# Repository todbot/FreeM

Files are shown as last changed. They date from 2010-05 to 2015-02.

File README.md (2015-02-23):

# FreeM: aka "BlinkM Battery Remote"
======================================

https://www.youtube.com/watch?v=3fSsRGN1ip0

(http://www.youtube.com/watch?v=3fSsRGN1ip0)

Documentation is kind of sparse at the moment.
So this kit is aimed at more advanced users right now.

The firmware "freem_a2" is the one you should use.
If you are using the FreeM Kit from FunGizmos, the chip is preprogrammed.

Otherwise, tune the Makefile for your AVR programmer if you're not using an
AVRISP mkII.  Then type "make program" to compile and program your chip.

From the header of the firmware, these are the basic features:
```
 * Remote control functions:  (Sony TV remotes only right now)
 * - POWER     - stop script & turn off blinkm
 * - CH  UP/DN - solid hue mode, cycle hue if held down
 * - VOL UP/DN - brightness up/down
 * - ENTER     -
 * - MUTE      - 
 * - Num keys  - do something interesting
 *   1 - random slowly changing mood light (calc'd in FreeM)
 *   2 - fast random colors
 *   3 - flashing beacon, use ch up/dn to change hue, press 3 again to start
 *   4 - yellow
 *   5 - aqua
 *   6 - purple
 *   7 - dim white
 *   8 - med white
 *   9 - bright white
 *   0 - play script 0 on BlinkM
 * 
 * Data Mode:
 * - Sending keycode of 0x07F7 escapes into data mode
 * - Sending keycode of 0x07F8 escapes out of data mode
 * - data format is: len,byte_0,byte_1,byte_2,...byte_len-1
 * - if len==4, then command is sent as a straight 3-arg BlinkM command,
 *   e.g. send binary 0x7F7,'c',0xFF,0x00,0xFF to fade BlinkM to purple
 * - data mode is still buggy and aggravating, but maybe interesting
 *
 * "BlinkM Battery Remote" - battir3 pcb layout
 * ---------------------------------------------
 * attiny45       -- function
 * pin 1 -- PB5   -- RESET
 * pin 2 -- PB3   -- PHOTOCELL  (unused)
 * pin 3 -- PB4   -- IRDETECT
 * pin 4 -- GND   -- GND
 * pin 5 -- PB0   -- SDA/MOSI    -- 
 * pin 6 -- PB1   -- MISO        -- LED1 & serial TX out
 * pin 7 -- PB2   -- SCK/SCL     -- 
 * pin 8 -- VCC   -- VCC
```

Assembly Tip:
   LED orientation: Cathode (short lead) faces the "led1" silkscreen printing on the PCB. 

Contact tod at thingm.com if you have any questions.

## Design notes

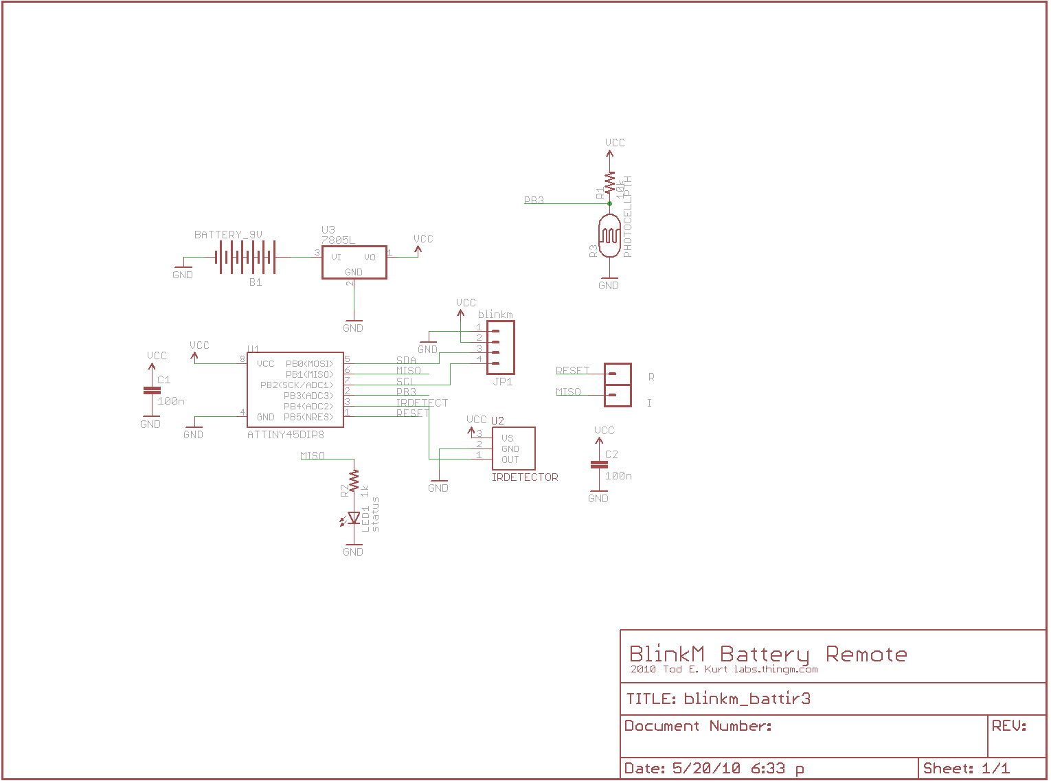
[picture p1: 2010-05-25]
schematic/blinkm_battir3.png

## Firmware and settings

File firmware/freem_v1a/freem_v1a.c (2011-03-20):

/**
 * freem_v1a.c -- FreeM: BlinkM Battery Remote firmware
 *
 * 
 * 2010, Tod E. Kurt, thingm.com
 *
 * Remote control functions:  (Sony TV remotes only right now)
 * - POWER     - stop script & turn off blinkm
 * - CH  UP/DN - solid hue mode, cycle hue if held down
 * - VOL UP/DN - brightness up/down
 * - ENTER     -
 * - MUTE      - 
 * - Num keys  - do something interesting
 *   1 - random slowly changing mood light (calc'd in FreeM)
 *   2 - fast random colors, ch up/dn to change speed
 *   3 - flashing beacon, use ch up/dn to change hue, press 3 again to start
 *   4 - fixed color, hold to change hue, vol/up dn to change brightness
 *   5 - flash once
 *   6 - purple
 *   7 - dim white, hold to change bright
 *   8 - med white, hold to change bright
 *   9 - bright white, hold to change bright
 *   0 - play script 0 on BlinkM
 * 
 *
 * CtrlM IR protocol:
 * ------------------
 * CtrlM Commands are 8 bytes long. 
 * These 8 bytes are sent out as two 32-bit word packets, 
 * using a modified 32-bit version of the Sony IR protocol.
 * Consisting of the bytes:
 * byte0 -- 0x55        - start byte
 * byte1 -- freem_addr  -
 * byte2 -- blinkm_addr -
 * byte3 -- blinkm_cmd  - 
 * byte4 -- blinkm_arg1 - blinkm arg1 (if not used, set to 0)
 * byte5 -- blinkm_arg2 - blinkm arg2 (if not used, set to 0)
 * byte6 -- blinkm_arg3 - blinkm arg3 (if not used, set to 0)
 * byte7 -- checksum    - simple 8-bit sum of bytes 0-6
 *
 *
 * buffer layout is like:  (na == don't matter, set to zero)
 *                  buf[0], buf[1],     buf[2],      [3],  [4], [5], [6],  [7]
 *  std command:     {0x55,  freem_addr, blinkm_addr, cmd,  a1,  a2,  a3,   chk}
 *  write freemaddr: {0x55,  freem_addr, 0xff,        0xff, na,  na,  na,   chk}
 *  set color spot:  {0x55,  freem_addr, 0xfe,        pos,  a1,  a2,  a3,   chk}
 *  play color spot: {0x55,  freem_addr, 0xfd,        pos, cmd,  na,  na,   chk}
 *
 *
 * Some LinkM.sh commands to try: (0x21 == '!'):
 *
 * Fade to purple (0xff,0x00,0xff):
 * ./linkm.sh -v --cmd "0x21,0x55,0,0,'c',0xff,0x00,0xff,0xb6" 
 *
 * Set colorspot 3 to 0x00,0xff,0xff:
 * ./linkm.sh -v --cmd "0x21,0x55,0,0xfe,3,0x00,0xff,0xff,0x54" 
 *
 * Play colorspot 3: 2nd way gives command, could be 'p'lay script
 * ./linkm.sh -v --cmd "0x21,0x55,0,0xfd,3,0x00,0x00,0x00,0x55" 
 * ./linkm.sh -v --cmd "0x21,0x55,0,0xfd,3,'c',0x00,0x00,0xb8" 
 *
 * Can also do: (with new CtrlM firmware that supports '^' and '*', 0x2a='*')
 * ./linkm.sh -v --cmd "0x2a,3,'p',0" 
 *
 * And, Set Colorspot:
 * ./linkm.sh -v --cmd "0x5e,3,0x98,0x76,0x54"  // with new ctrlm '^' == 0x53
 * ./linkm.sh -v --cmd "0x21,0x55,0,0xfe,3,0x98,0x76,0x54,0xb8" // by hand
 * 
 *
 * FreeM ATtiny85 pinout
 * ----------------------
 * attiny85       -- function                         -- header label
 * pin 1 -- PB5   -- RESET                            --  R
 * pin 2 -- PB3   -- PHOTOCELL  (unused)              -- 
 * pin 3 -- PB4   -- IRDETECT                         --  
 * pin 4 -- GND   -- GND                              --  -
 * pin 5 -- PB0   -- SDA/MOSI                         --  d 
 * pin 6 -- PB1   -- MISO  -- LED1 / serial TX out    --  I
 * pin 7 -- PB2   -- SCK/SCL                          --  c
 * pin 8 -- VCC   -- VCC                              --  +
 *
 */

#include <avr/io.h>
#include <avr/interrupt.h>
#include <avr/eeprom.h>
#include <util/delay.h>    // for _delay_ms()
#include <stdint.h>        // for types like uint8_t, etc.
#include <stdlib.h>        // for rand()

// set DEBUG to 0 to disable all debug info and save code space
// set DEBUG to 1 to enable serial debugging on pin 6 (PB1)
// set DEBUG to 2 to enable serial logging off all keys received 
#define DEBUG 0
#define DEBUG_IR 0

#define LED_PIN  PB1
#define LED_PORT PORTB
#define LED_DDR  DDRB

// these must be defined before including i2cmaster_bitbang
#define I2C_DDR  DDRB
#define I2C_PIN  PINB
#define I2C_PORT PORTB
#define I2C_CLK  PB2    
#define I2C_DAT  PB0

// these must be defined before inclding irsony
#define IR_RCV   PB4
#define IR_PORT  PORTB
#define IR_DDR   DDRB
#define IR_PIN   PINB


#if DEBUG>0
// must define this before including softuart.h
#if F_CPU == 500000
#define _baudRate  2400   // if F_CPU=500kHz, doesn't work at other baudrates
#endif
#if F_CPU == 8000000
#define _baudRate  38400  // if F_CPU=8MHz
#endif
#include "softuart.h"
#else  // if DEBUG==0 nuke the func calls so they're just ignored
#define softuart_init()
#define softuart_putc(x)
#define softuart_puts(x)
#define softuart_putsP(x)
#define softuart_printHex(x)
#define softuart_printHex16(x)
#endif


#include "i2cmaster_bitbang.h"
#include "irsony.h"


// I2C address of blinkm, or 0 to address all blinkms
uint8_t i2csendaddr = 0;

#include "blinkm_funcs.h"   // uses i2csendaddr


 //  The timing information for timer to fire periodically 
#if F_CPU == 500000
#define MILLIS_PER_T1OVF       4      // actually 4.1msec
#endif
#if F_CPU == 8000000
#define MILLIS_PER_T1OVF       2      // actually 4.048 msec
#endif

static volatile uint32_t millis = 0;  // current time, set by timer ISR 


//-----------------------------------------------------

#define FADESPEED_DEFAULT    10
#define FADESPEED_RANDMOOD    2
#define FADESPEED_RANDFAST  100

#define MILLIS_MOOD        4000
#define MILLIS_FAST         300

#define KEYMILLIS_MIN       200
#define KEYMILLIS_HOLD     1200 // millis to be considered a hold press

// the different modes FreeM can be in
enum {
    MODE_OFF,
    MODE_RANDMOOD,
    MODE_RANDFAST,
    MODE_FLASH,
    MODE_FLASHONCE,
    MODE_NUMKEY,
    MODE_WHITE,
    MODE_HSB,
    MODE_PLAYSCRIPT,
};
uint8_t mode = MODE_OFF; 

uint32_t changemillis;   // the last time we changed, for RANDMOOD, etc.
uint32_t changemillisdiff;

uint16_t key;            // keypress
uint16_t keylast;       // the previous keypress
uint32_t keylast_millis;
uint32_t keymillis;      // last time a key was pressed
uint8_t keyheld;


uint8_t  hue = 0;        // current hue
uint8_t  bri = 255;      // current brightness
uint8_t  bris;

// address of FreeM
uint8_t freem_addr  = 0x80;

// buf to store copy of incoming data packet
uint8_t buf[8];

typedef struct _rgb_t {
    uint8_t r;
    uint8_t g;
    uint8_t b;
} rgb_t;

/*  no, cannot do this because ctrlm IR protocol doesn't have enough bytes
typedef struct _blinkm_cmd_t {
    uint8_t c;
    uint8_t a1;
    uint8_t a2;
    uint8_t a3;
} blinkm_cmd_t;
*/

// address of this FreeM
uint8_t  ee_freem_addr         EEMEM = 0x7d;  // FIXME: make this match freem_ad
rgb_t ee_colorspots[16] EEMEM;


// -----------------------------------------------------

static void statled_set(uint8_t v)
{
    if(v) LED_PORT |=  _BV( LED_PIN );
    else  LED_PORT &=~ _BV( LED_PIN );
} 
static void statled_toggle(void)
{
    LED_PORT ^= _BV(LED_PIN);
}

// a little hello fanfare
static void fanfare( uint8_t times ) 
{
    for( int i=0;i<times; i++ ) {
#if DEBUG > 0
        softuart_putc('*');
#else
        statled_set(1);
#endif
        blinkm_setRGB( 0x09,0x09,0x09);
        _delay_ms(150);
#if DEBUG > 0
#else
        statled_set(0);
#endif
        blinkm_setRGB( 0x00,0x00,0x00);
        _delay_ms(150);
    }
}


//
// Parse the key presses from IR remote
//
static void handle_key(void)
{
    if( (millis - keylast_millis) > KEYMILLIS_HOLD ) {
        keyheld = 0;
    }

    key = ir_getdata( buf );
    if( key == IR_NONE ) {       // no IR data of any kind
        return;
    }
    
    if( key == IR_GOT_DATA ) {  // got CtrlM 8-byte packet
#if DEBUG >0
        softuart_putsP("ctrlm:");
        //softuart_printHex( buf[0] ); softuart_putc(',');  // start byte 0x55
        softuart_printHex( buf[1] ); softuart_putc(',');    // freem_addr
        softuart_printHex( buf[2] ); softuart_putc(',');    // blinkm_addr
        softuart_printHex( buf[3] ); softuart_putc(',');    // blinkm_cmd
        softuart_printHex( buf[4] ); softuart_putc(',');    // blinkm_arg1
        softuart_printHex( buf[5] ); softuart_putc(',');    // blinkm_arg2
        softuart_printHex( buf[6] ); softuart_putc(':');    // blinkm_arg3
        //softuart_printHex( buf[7] ); softuart_putc('\n'); // checksum
#else
        statled_set(1);
#endif

        // reminder, buffer is like: {0x55,faddr,baddr, cmd,  a1, a2, a3, chk}
        //                           buf[0], [1],  [2], [3], [4],[5],[6], [7]
        mode = MODE_OFF;
        // set freem addr cmd
        if( buf[2] == 0xff && buf[3] == 0xff ) {   // FIXME: document this!
            softuart_putsP("new freem addr\n");
            freem_addr = buf[1];
            eeprom_write_byte( &ee_freem_addr, freem_addr ); // write address
            fanfare(5);  // let people know we did the deed
        }
        // check freem addr to see if its mine or broadcast
        else if( buf[1] == freem_addr || buf[1] == 0 ) {  // me or broadcast
            
            // set colorspot 
            if( buf[2] == 0xfe ) {       // 0xfe == set color slot freem cmd
                uint8_t pos = buf[3];
                rgb_t spot;  
                spot.r = buf[4]; spot.g = buf[5]; spot.b = buf[6];
#if DEBUG >0
                softuart_putsP("set colorspot");
                softuart_printHex(pos);
                softuart_putc(' ');
                softuart_printHex( (int) &(ee_colorspots[pos]) );
                softuart_printHex(spot.r);
                softuart_printHex(spot.g);
                softuart_printHex(spot.b);
#endif
                eeprom_write_block( &spot, &(ee_colorspots[pos]),sizeof(rgb_t));
                // FIXME: flash stat LED in recognition
            }
            // play colorspot
            else if( buf[2] == 0xfd ) {  // 0xfd == play color slot freem cmd
                uint8_t pos = buf[3];
                uint8_t cmd = buf[4]; 
                rgb_t spot;
                eeprom_read_block(  &spot, &(ee_colorspots[pos]),sizeof(rgb_t));
#if DEBUG >0 
                softuart_putsP("play colorspot");
                softuart_printHex(pos); 
                softuart_putc(' '); 
                softuart_printHex( (int) &(ee_colorspots[pos]) );      
                softuart_printHex(spot.r);
                softuart_printHex(spot.g);
                softuart_printHex(spot.b);
#endif
                if( cmd==0 ) { cmd = 'c'; }
                blinkm_sendCmd3( cmd, spot.r, spot.g, spot.b );
            }
            else { // normal cmd
                softuart_putsP("me!");
                i2csendaddr = buf[2];
                if( buf[3] == 'f' ) {   // FIXME: hack
                    blinkm_setFadespeed( buf[4] );  
                } else { 
                    blinkm_sendCmd3( buf[3], buf[4], buf[5], buf[6] );
                }
            }
        }
        
#if DEBUG >0
        softuart_putc('\n');
#else 
        statled_set(0);
#endif
        return;  // done with data mode, don't continue on

    } // if( key == IR_GOT_DATA )

    //
    // Otherwise, it's an RC code
    //
    // okay, we have these cases:
    // no presses for long time, then keypress
    // hold-down key, same key every 50ms or so
    // press key, wait a little bit, press key again
    // press key, press another key

    if( key == keylast ) {  // same key
        if( (millis - keylast_millis) < KEYMILLIS_MIN ) { // a repeat
            if( millis - keymillis > KEYMILLIS_HOLD ) { // since start of key
                keyheld = 1;
            }
        }
        else {             // or press and press again, reset key start time
            keymillis = millis;
        }
    }
    else {                  // a new key, reset
        keymillis = millis;
        keyheld = 0;
    }

    keylast = key;
    keylast_millis = millis;

#if DEBUG > 1
    softuart_puts("k:"); softuart_printHex16( key ); softuart_putc('\n');
#else
    statled_set(1);
#endif

    if( !(key == IRKEY_VOLUP || key == IRKEY_VOLDN) ) { 
        blinkm_stopScript();
        blinkm_setFadespeed( FADESPEED_DEFAULT );
    }

    if(      key == IRKEY_POWER ) {
        softuart_putsP("off\n");
        mode = MODE_OFF;
        blinkm_turnOff();
    }
    else if( key == IRKEY_CHUP ) {    // increase hue, for current mode
        if( mode == MODE_OFF ) mode = MODE_HSB;
        hue+=2;
        softuart_putsP("h+:"); softuart_printHex(hue); softuart_putc('\n');
    }
    else if( key == IRKEY_CHDN ) {    // decrease hue, for current mode
        if( mode == MODE_OFF ) mode = MODE_HSB;
        hue-=2;
        softuart_putsP("h-:"); softuart_printHex(hue); softuart_putc('\n');
    }
    else if( key == IRKEY_VOLUP ) {   // increase brightness, for current mode
        if( mode == MODE_OFF ) mode = MODE_HSB;
        if( bri < 253 ) bri+=3;
        else bri = 255;
        softuart_putsP("b+:"); softuart_printHex(bri); softuart_putc('\n');
    }
    else if( key == IRKEY_VOLDN ) {   // increase brightness, for current mode
        if( mode == MODE_OFF ) mode = MODE_HSB;
        if( bri > 2 ) bri-=3;
        else bri = 0;
        softuart_putsP("b-:"); softuart_printHex(bri); softuart_putc('\n');
    }
    else if( key == IRKEY_ONE ) {     // mode: random mood light 
        softuart_putsP("mood\n");
        mode = MODE_RANDMOOD;
        if( bri == 0 ) bri = 255;     // fix brightness on startup
    }
    else if( key == IRKEY_TWO ) {     // mode: fast random 
        softuart_putsP("rand\n");
        mode = MODE_RANDFAST;
        if( bri == 0 ) bri = 255;     // fix brightness on startup
        if( keyheld ) {  // reset hue/bri on holding key
            hue = 0;  
            bri = 255;
        }
    }
    else if( key == IRKEY_THREE ) {   // mode: beacon flash
        softuart_putsP("flash\n");
        mode = MODE_FLASH;
        if( keyheld ) {  // reset hue/bri on holding key
            hue = 0;  
            bri = 255;
        }
    }
    else if( key == IRKEY_FOUR ) {    // mode: fixed color
        softuart_putsP("hsb\n");
        softuart_printHex16(millis); softuart_putc(',');
        softuart_printHex16(keymillis); softuart_putc(',');
        softuart_printHex16(keylast_millis); softuart_putc('\n');
        mode = MODE_HSB;
        if( bri == 0 ) bri = 255;
        if( keyheld ) {  // reset hue/bri on holding key
            softuart_putc('+');
            hue+=2; 
        }
    }
    else if( key == IRKEY_FIVE ) {     // random color change  
        softuart_putsP("rand1\n");
        mode = MODE_HSB;
        bri = rand();
        hue = rand();
    }
    else if( key == IRKEY_SIX ) {   // mode: single flash at color
        softuart_putsP("flash1\n");
        mode = MODE_FLASHONCE;
        changemillis = 0;
        if( keyheld ) {  // reset hue/bri on holding key
            hue = 0;
            bri = 255;
        }
    }
    else if( key == IRKEY_SEVEN ) {  // low-white at vol up/dn brightness
        softuart_putsP("lwhite\n");
        mode = MODE_WHITE;
        bri = 0x01;
        blinkm_fadeToRGB( bri, bri, bri );
    }
    else if( key == IRKEY_EIGHT ) {  // mid-white at vol up/dn brightness
        softuart_putsP("mwhite\n");
        mode = MODE_WHITE;
        bri = 0x80;
        blinkm_fadeToRGB( bri, bri, bri );
    }
    else if( key == IRKEY_NINE ) {   // low-white at vol up/dn brightness
        softuart_putsP("white\n");
        mode = MODE_WHITE;
        blinkm_fadeToRGB( bri, bri, bri );
        if( keyheld ) { // make brighter on key hold
            bri += 10;               // will just wrap around
        }
    }
    else if( key == IRKEY_ZERO ) {
        softuart_putsP("play0\n");
        mode = MODE_PLAYSCRIPT;
        blinkm_setFadespeed( FADESPEED_DEFAULT );
        blinkm_playScript( 0,0 );
    }

    key = 0;

#if DEBUG > 0
#else
    statled_set(0);
#endif

}

// ------------------------------------------------------


//
// 
//
int main( void )
{
    CLKPR = _BV( CLKPCE );                  // enable clock prescale change
#if F_CPU == 500000
    CLKPR = _BV(CLKPS2) ;                   // div clock by 16 (8MHz -> 0.5MHz)
#else
    CLKPR = 0;                              // full speed (8MHz)
#endif

#if F_CPU == 500000
    TCCR1 |= _BV(CS12);                     // clock/8  see calc below @0.5MHz
#endif
#if F_CPU == 8000000
    TCCR1 |= _BV(CS12)|_BV(CS11)|_BV(CS10); // clock/64 see calc below @8MHz
#endif

    TIFR  |= _BV( TOV1 );       // clear interrupt flag
    TIMSK |= _BV( TOIE1 );      // enable timer 1 overflow interrupt

    sei();              // enable interrupts 

    LED_DDR |= _BV( LED_PIN );  // make output

    softuart_init();
    softuart_putsP("\nfreem_v1\n");

    _delay_ms(300);  // wait for power to stabilize before doing i2c

    // load up our address
    freem_addr = eeprom_read_byte( &ee_freem_addr );
    softuart_putsP("addr:"); softuart_printHex(freem_addr);softuart_putc('\n');

    ir_init();

    i2c_init();

#if DEBUG > 1
    softuart_puts("300ms? ");
    _delay_ms(300);     // timing test, just chill a bit, yo
    softuart_printDec16( millis-lastmillis );   // should be close to 300
#endif

    blinkm_turnOff();

    fanfare( 3 );

    mode = MODE_RANDMOOD;  // start out in moodlight mode
    changemillis = millis - 2*MILLIS_MOOD;


    // loop forever 
    for( ; ; ) {

        handle_key();  // read a key, maybe change mode, or hue/bri

        changemillisdiff = millis - changemillis;

        // FIXME: this could be refactored to be more efficient
        if( mode == MODE_RANDMOOD ) { 
            if( changemillisdiff > MILLIS_MOOD ) {
                softuart_putsP("rhb:");
                softuart_printHex(hue); softuart_putc(',');
                softuart_printHex(bri); softuart_putc('\n');
                changemillis = millis;
                hue = rand();
            }
            blinkm_setFadespeed( FADESPEED_RANDMOOD );
            blinkm_fadeToHSB( hue, 255, bri );
        }
        else if( mode == MODE_RANDFAST ) { 
            if( changemillisdiff > MILLIS_FAST ) { 
                changemillis = millis;
                hue = rand();
                blinkm_setFadespeed( FADESPEED_RANDFAST );
                blinkm_fadeToHSB( hue, 255, bri );
            }
            blinkm_setFadespeed( FADESPEED_RANDFAST );
            blinkm_fadeToHSB( hue, 255, bri );
        }
        else if( mode == MODE_WHITE ) {
            blinkm_setFadespeed( FADESPEED_RANDMOOD );
            blinkm_fadeToRGB( bri, bri, bri );
        }
        else if( mode == MODE_HSB ) {
            blinkm_setFadespeed( FADESPEED_RANDMOOD );
            blinkm_fadeToHSB( hue, 255, bri );
        }
        else if( mode == MODE_FLASH ) {
            if( changemillisdiff > MILLIS_FAST ) { 
                softuart_putsP("ms:"); 
                softuart_printHex16(changemillisdiff); softuart_putc(',');
                softuart_printHex16(millis); softuart_putc('\n');
                changemillis = millis;
                blinkm_setFadespeed( FADESPEED_RANDFAST );
                if( keyheld ) {
                    blinkm_fadeToHSB( hue, 255, bri);
                } else {
                    bris = (bris>10) ? 0 : bri;
                    blinkm_fadeToHSB( hue, 255, bris);
                }
            }
        }
        else if( mode == MODE_FLASHONCE ) {
            if( changemillis == 0 ) {                         // start
                blinkm_setFadespeed( FADESPEED_RANDFAST );
                blinkm_fadeToHSB( hue, 255, bri);
                changemillis = millis;
            }
            else if( changemillisdiff > MILLIS_FAST ) {  //stop
                blinkm_fadeToHSB( 0,0,0);
                mode = MODE_OFF;
                changemillis = 0;
            }
        }

        
    } // for
}


//
// Timer1 Overflow interrupt
// Called on overflow (256 ticks) of Timer1. 0.5MHz internal clock 
// We want approximately 50 milliseconds between measurements
// calculate with '1/(0.5e6/256/_1024_) * 1000' to get milliseconds
// At 0.5MHz:
//  CS      11    set (clk/    2), Timer1 ovfs @976.6 Hz   (  1.0ms)
//  CS   12       set (clk/    8), Timer1 ovfs @244.1 Hz   (  4.1ms)
//  CS   12 11 10 set (clk/   64), Timer1 ovfs @ 30.5 Hz   ( 32.7ms)*
//  CS13       10 set (clk/  256), Timer1 ovfs @  7.6 Hz   (131.0ms)
//  CS13    11    set (clk/  512), Timer1 ovfs @  3.8 Hz   (262.1ms) 
//  CS13    11 10 set (clk/ 1024), Timer1 ovfs @  1.9 Hz   (524.3ms)
//  CS13 12 11    set (clk/ 8192), Timer1 ovfs @
//
// At 8MHz:
//  CS   12 11 10 set (clk/   64), Timer1 ovfs @ 30.5 Hz   ( 32.7ms)*
//
// See table 15-2  in ATtiny45 datasheet for more
ISR(TIMER1_OVF_vect)
{
    millis += MILLIS_PER_T1OVF;
}


//-----------------------------------------------------
// utility funcs
//

// this is a really cheapie rand
// using this instead of real rand() saves 300 bytes
/*
static uint8_t rand8bit(void)
{
    static int16_t rctx;
    if( rctx == 0 ) rctx = 1234; // 123467;
    int hi = (rctx<<1) / 123;
    int lo = (rctx<<1) % 123;
    int  x = 1687 * lo - 286 * hi;
    rctx = x;
    return x;
}
#define rand(x) rand8bit(x)
*/

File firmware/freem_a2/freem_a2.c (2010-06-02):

/**
 * freem_a2.c -- FreeM: BlinkM Battery Remote demonstration firmware
 *               Use with "BlinkM Battery Remote" (battir3) circuit
 * 
 * 2010 Tod E. Kurt, labs.thingm.com
 *
 * Remote control functions:  (Sony TV remotes only right now)
 * - POWER     - stop script & turn off blinkm
 * - CH  UP/DN - solid hue mode, cycle hue if held down
 * - VOL UP/DN - brightness up/down
 * - ENTER     -
 * - MUTE      - 
 * - Num keys  - do something interesting
 *   1 - random slowly changing mood light (calc'd in FreeM)
 *   2 - fast random colors
 *   3 - flashing beacon, use ch up/dn to change hue, press 3 again to start
 *   4 - yellow
 *   5 - aqua
 *   6 - purple
 *   7 - dim white
 *   8 - med white
 *   9 - bright white
 *   0 - play script 0 on BlinkM
 * 
 * Data Mode:
 * - Sending keycode of 0x07F7 escapes into data mode
 * - Sending keycode of 0x07F8 escapes out of data mode
 * - data format is: len,byte_0,byte_1,byte_2,...byte_len-1
 *
 * "BlinkM Battery Remote" - battir3 pcb layout
 * ---------------------------------------------
 * attiny45       -- function
 * pin 1 -- PB5   -- RESET
 * pin 2 -- PB3   -- PHOTOCELL  (unused)
 * pin 3 -- PB4   -- IRDETECT
 * pin 4 -- GND   -- GND
 * pin 5 -- PB0   -- SDA/MOSI    -- 
 * pin 6 -- PB1   -- MISO        -- LED1 & serial TX out
 * pin 7 -- PB2   -- SCK/SCL     -- 
 * pin 8 -- VCC   -- VCC
 *
 */

#include <avr/io.h>
#include <avr/interrupt.h>
#include <util/delay.h>    // for _delay_ms()
#include <stdint.h>        // for types like uint8_t, etc.
#include <stdlib.h>        // for rand()

// set DEBUG to 0 to disable all debug info and save code space
// set DEBUG to 1 to enable serial debugging on pin 6 (PB1)
// set DEBUG to 2 to enable serial logging off all keys received 
#define DEBUG 1

#define LED_PIN  PB1
#define LED_PORT PORTB
#define LED_DDR  DDRB

// these must be defined before including i2cmaster_bitbang
#define I2C_DDR  DDRB
#define I2C_PIN  PINB
#define I2C_PORT PORTB
#define I2C_CLK  PB2    
#define I2C_DAT  PB0

// these must be defined before inclding irsony
#define IR_RCV    PB4
#define IR_PORT   PORTB
#define IR_DDR    DDRB
#define IR_PIN    PINB

#if DEBUG>0
// must define this before including softuart.h
#if F_CPU == 500000
#define _baudRate  2400 // if F_CPU=500kHz
#endif
#if F_CPU == 8000000
#define _baudRate  38400  // if F_CPU=8MHz
#endif
#include "softuart.h"
#else  // if DEBUG==0 nuke the func calls so they're just ignored
#define softuart_init()
#define softuart_putc(x)
#define softuart_puts(x)
#define softuart_printHex(x)
#define softuart_printHex16(x)
#endif

#include "i2cmaster_bitbang.c"
#include "irsony.c"


//  The timing information for timer to fire periodically 
#define MILLIS_PER_T1OVF       4      // actually 4.1msec
static volatile uint16_t millis = 0;  // current time, set by timer ISR 
static volatile uint8_t t1ovf_count;  
static uint16_t lastmillis;           // the previous time we did something

//-----------------------------------------------------

#define FADESPEED_DEFAULT    10
#define FADESPEED_RANDMOOD    2
#define FADESPEED_RANDFAST  100

#define MILLIS_MOOD  4000
#define MILLIS_FAST   300

// the different modes FreeM can be in
enum {
    MODE_OFF,
    MODE_HUE,
    MODE_RANDMOOD,
    MODE_RANDFAST,
    MODE_FLASH,
    MODE_NUMKEY,
    MODE_PLAYSCRIPT,
    MODE_DATA,
};
uint8_t mode = MODE_OFF; 

uint16_t key;            // keypress
uint8_t hue;             // current hue
uint8_t bri;             // current brightness
uint16_t changemillis;   // the last time we changed, for RANDMOOD, etc.

// I2C address of blinkm, or 0 to address all blinkms
uint8_t i2csendaddr = 0;

//-----------------------------------------------------
// utility funcs
//

// this is a really cheapie rand
// using this instead of real rand() saves 300 bytes
/*
static uint8_t rand8bit(void)
{
    static int16_t rctx;
    if( rctx == 0 ) rctx = 1234; // 123467;
    int hi = (rctx<<1) / 123;
    int lo = (rctx<<1) % 123;
    int  x = 1687 * lo - 286 * hi;
    rctx = x;
    return x;
}
#define rand(x) rand8bit(x)
*/

//-----------------------------------------------------
// blinkm funcs
//

static void blinkm_stopScript(void)
{
    i2c_start();
    i2c_write((i2csendaddr<<1));  // FIXME: check return value
    i2c_write('o');  
    i2c_stop();
}

static void blinkm_sendCmd3( uint8_t c, uint8_t a1, uint8_t a2, uint8_t a3 )
{
    i2c_start();
    i2c_write((i2csendaddr<<1));  // FIXME: check return value
    i2c_write( c );  
    i2c_write( a1 );       
    i2c_write( a2 );       
    i2c_write( a3 );       
    i2c_stop();        
}

static void blinkm_setFadespeed( uint8_t f ) 
{
    i2c_start();
    i2c_write((i2csendaddr<<1));  // FIXME: check return value
    i2c_write('f');
    i2c_write(f);
    i2c_stop();    

}
static void blinkm_fadeToRGB( uint8_t r, uint8_t g, uint8_t b )
{
    blinkm_sendCmd3( 'c', r,g,b );
}

static void blinkm_fadeToHSB( uint8_t h, uint8_t s, uint8_t b )
{
    blinkm_sendCmd3( 'h', h,s,b );
}

static void blinkm_setRGB(  uint8_t r, uint8_t g, uint8_t b )
{
    blinkm_sendCmd3( 'n', r,g,b );
}

static void blinkm_playScript( uint8_t p, uint8_t n )
{
    blinkm_sendCmd3( 'p', p,0,n );
}

static void blinkm_turnOff(void)
{
    blinkm_stopScript();
    blinkm_setRGB( 0,0,0 );
}


// -----------------------------------------------------

static void statled_set(uint8_t v)
{
    if(v) LED_PORT |=  _BV( LED_PIN );
    else  LED_PORT &=~ _BV( LED_PIN );
} 
static void statled_toggle(void)
{
    LED_PORT ^= _BV(LED_PIN);
}

//
// Attempt to have a litle datapath in there for sending blinkm cmds over IR
// Doesn't work very reliably yet
//
static void get_data(void)
{
    uint8_t i,j,d[8];                  // the data, at most 8 bytes
    uint16_t v,len=0;

    j=200;
    while( !(len = ir_getkey()) ) {      // length of packet
        _delay_ms(1);
        j--;
        if( j == 0 )                     // FIXME: dumb timeout
            goto dataerror;
    }
    len = (len>8) ? 8 : len;             // enforce bounds

    for( i=0; i<len; i++ ) {  
        j = 200;
        while( !(v=ir_getkey()) ) {     // wait for key then store it
            _delay_ms(1);
            j--;
            if( j == 0 )                // FIXME: dumb timeout
                goto dataerror2;
        }
        d[i] = v;
    }


 datadone:
    /* // this takes too long, 2400 bps sucks
    softuart_printHex(len);
    softuart_putc('=');
    for( i=0;i<len;i++) {
        softuart_printHex( d[i] ); softuart_putc(',');
    }
    */
    // now do something with that data
    if( len == 4 ) { 
        softuart_putc('*');
        blinkm_sendCmd3( d[0], d[1],d[2],d[3] );
    }
    mode = MODE_OFF;
    return;

 dataerror2:
    softuart_putc('!');
 dataerror:
    softuart_putc('!');
    goto datadone;  // so we can at least see the partial data
}

//
// Parse the key presses from IR remote
//
static void handle_key(void)
{
    key = ir_getkey();
    if( key==0 )  // no key
        return;
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

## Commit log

2010-05-25 added freem
    [blinkm_battir1.brd, blinkm_battir1.sch, blinkm_battir2.brd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]
2010-05-26 added many new features to freem_a2, just about ready for burning into the kits
    [freem_a2.c]
2010-05-27 fixed timekeeping issues, added rudimentary data transfer mode (still lossy)
    [freem_a2.c]
2010-06-02 fixed desc of data mode
    [freem_a2.c]
2010-06-26 LED orientation assembly tip.
2010-07-06 added freem_v1
    [freem_v1.brd, freem_v1.sch]
2010-09-04 added freem_p5, does in-interrupt parsing of code, no more irtimes[] buffer
2010-09-06 freem_v1: version sent to apcircuits for proto
    [freem_v1.brd, freem_v1.sch]
2010-09-12 freem_p6: better protocol, fixed statled use, moved blinkm_funcs to their own file
    [freem_p6.c]
2010-09-13 freem_p6: fixed statled issue when in debug mode, added back in startup delay to let power stabilize
    [freem_p6.c]
2010-09-14 freem_p7: switched to 64-bit all-at-once protocol, works as well as it can work i think
2010-09-15 added imgs
    [freem_v1.brd]
2010-09-18 fixed up RC mode commands
    [freem_p7.c]
2010-09-22 added fuse file
2010-09-22 freem_v1: fixed pkging for fuses
2010-09-25 added soft i2c demo
2010-10-05 blinkmcommunicator: added i2cscan ability
